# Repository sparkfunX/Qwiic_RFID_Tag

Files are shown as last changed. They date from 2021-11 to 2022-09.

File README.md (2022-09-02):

# SparkX ST25DV64KC Dynamic NFC/RFID Tag

<p align="center">
    <a href="https://github.com/sparkfunX/Qwiic_RFID_Tag/blob/master/LICENSE" alt="License">
        </a>
    <a href="https://twitter.com/intent/follow?screen_name=sparkfun">
                    </a>
</p>

<table class="table table-hover table-striped table-bordered">
    <tr align="center">
     <td></td>
    </tr>
    <tr align="center">
        <td><a href="https://www.sparkfun.com/products/19035">SparkFun Qwiic Dynamic RFID Tag - ST25DV64KC (SPX-19035)</a></td>
    </tr>
</table>

The STMicroelectronics ST25DV _**dynamic**_ Near Frequency Communication / Radio Frequency Identification tag ICs are awesome! The ST25DV64KC offers 64-kBit (8-kBytes) of EEPROM memory which can be accessed over both I2C and RF (NFC)! It's a state-of-the-art tag which conforms to ISO/IEC 15693 or NFC Forum Type 5 recommendations. You can read and write the tag's memory using NFC even while the tag is powered down or disconnected!

The EEPROM memory can be divided into four areas, each of which can have different levels of protection applied. Want to store your data so everyone has read and write access over both I2C and RF? You can do that.
In fact, that's the default! Want to store your data in an area which can only be read if you know the password, and cannot be written to (via RF)? You can do that too!

Our [Arduino Library](https://github.com/sparkfun/SparkFun_ST25DV64KC_Arduino_Library) provides all of the methods you need to read and write the user memory, control the read and write permissions, alter the area sizes and apply password control. Not only that! We've included extra methods which will let you read and write **NDEF (NFC Forum Data Exchange Format) URI, WiFi and Text records** which your smart phone can understand!

Do you want your project to be able to log up to 8-kBytes of data (via I2C) and then be able to read it using your smart phone - even if your project is powered off? Our library lets you do that!

Do you want to be able to write WiFi credentials (SSID and Password) into tag memory using your smart phone and then to be able to read them over I2C so your Arduino board can join the network? With our library you can do that too!

Do you want to be able to manufacture and test your product and then program it with keys or other credentials just before you ship? We've got you covered.

Are you developing equipment or appliances for the home? Would you like to store diagnostic information so that the repair engineer can access it using their smart phone? Our library lets you do that! Would you like the customer to be able to read the diagnostics with _their_ smart phone and then email them to you? Our library will let you do that too! (Apart from the email bit - obvs.. You will need to add that bit yourself.)

Are you designing a poster for your project? Do you want to be able to program your tag using Arduino and then stick it to your poster so people can interact with it? Hey, we've got you covered there too!

## Arduino Library Documentation

A full library use overview, API reference guide and key example walk-throughs are available on GitHub Pages - [sparkfun.github.io/SparkFun_ST25DV64KC_Arduino_Library](https://sparkfun.github.io/SparkFun_ST25DV64KC_Arduino_Library/)

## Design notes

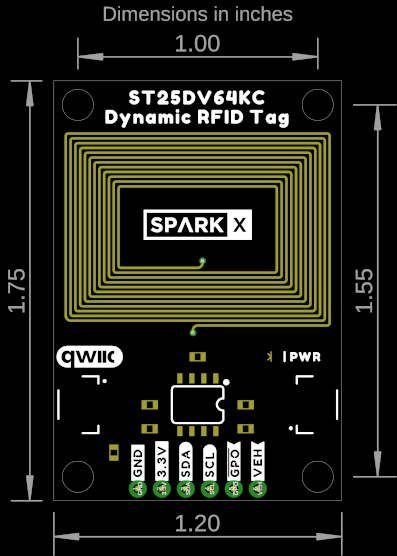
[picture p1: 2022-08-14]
Hardware/Dimensions.png

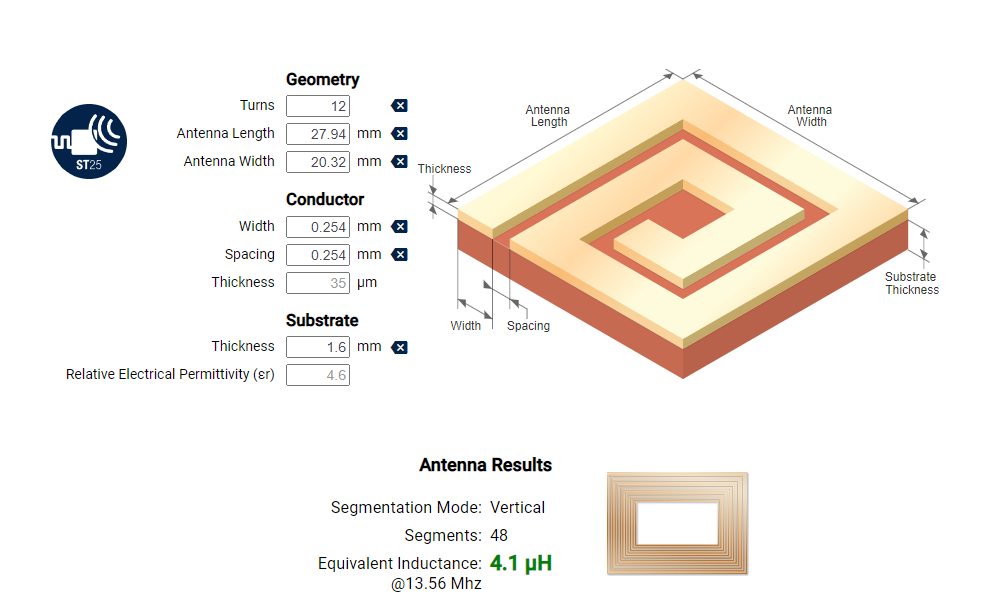
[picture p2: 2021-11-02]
Documents/Antenna design.png

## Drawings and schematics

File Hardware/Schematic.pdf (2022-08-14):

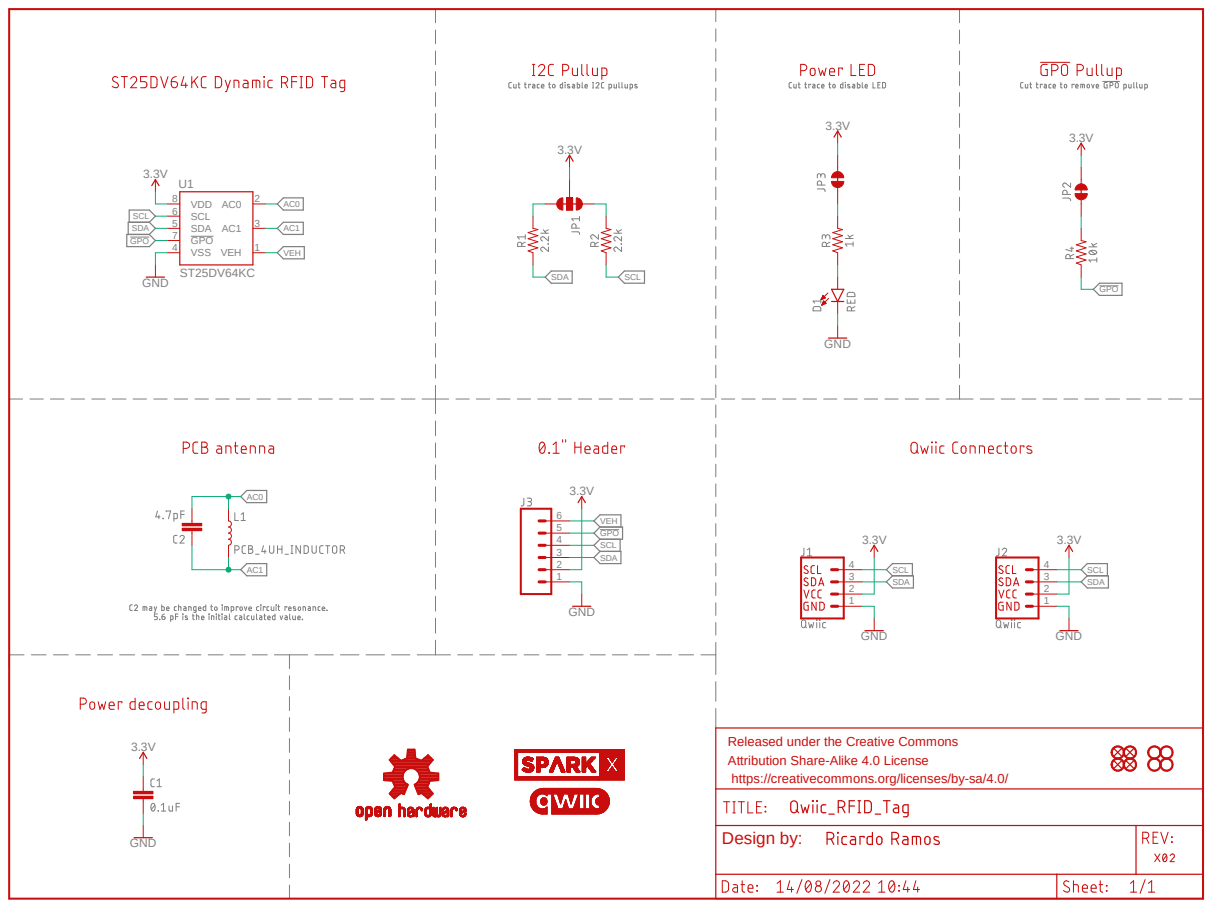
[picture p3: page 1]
GND; VDD 8 SCL 6 SDA 5 GPO 7; VSS 4; VEH; SCL; SDA; GPO; Released under the Creative Commons; Design by:

Attribution Share-Alike 4.0 License
https://creativecommons.org/licenses/by-sa/4.0/

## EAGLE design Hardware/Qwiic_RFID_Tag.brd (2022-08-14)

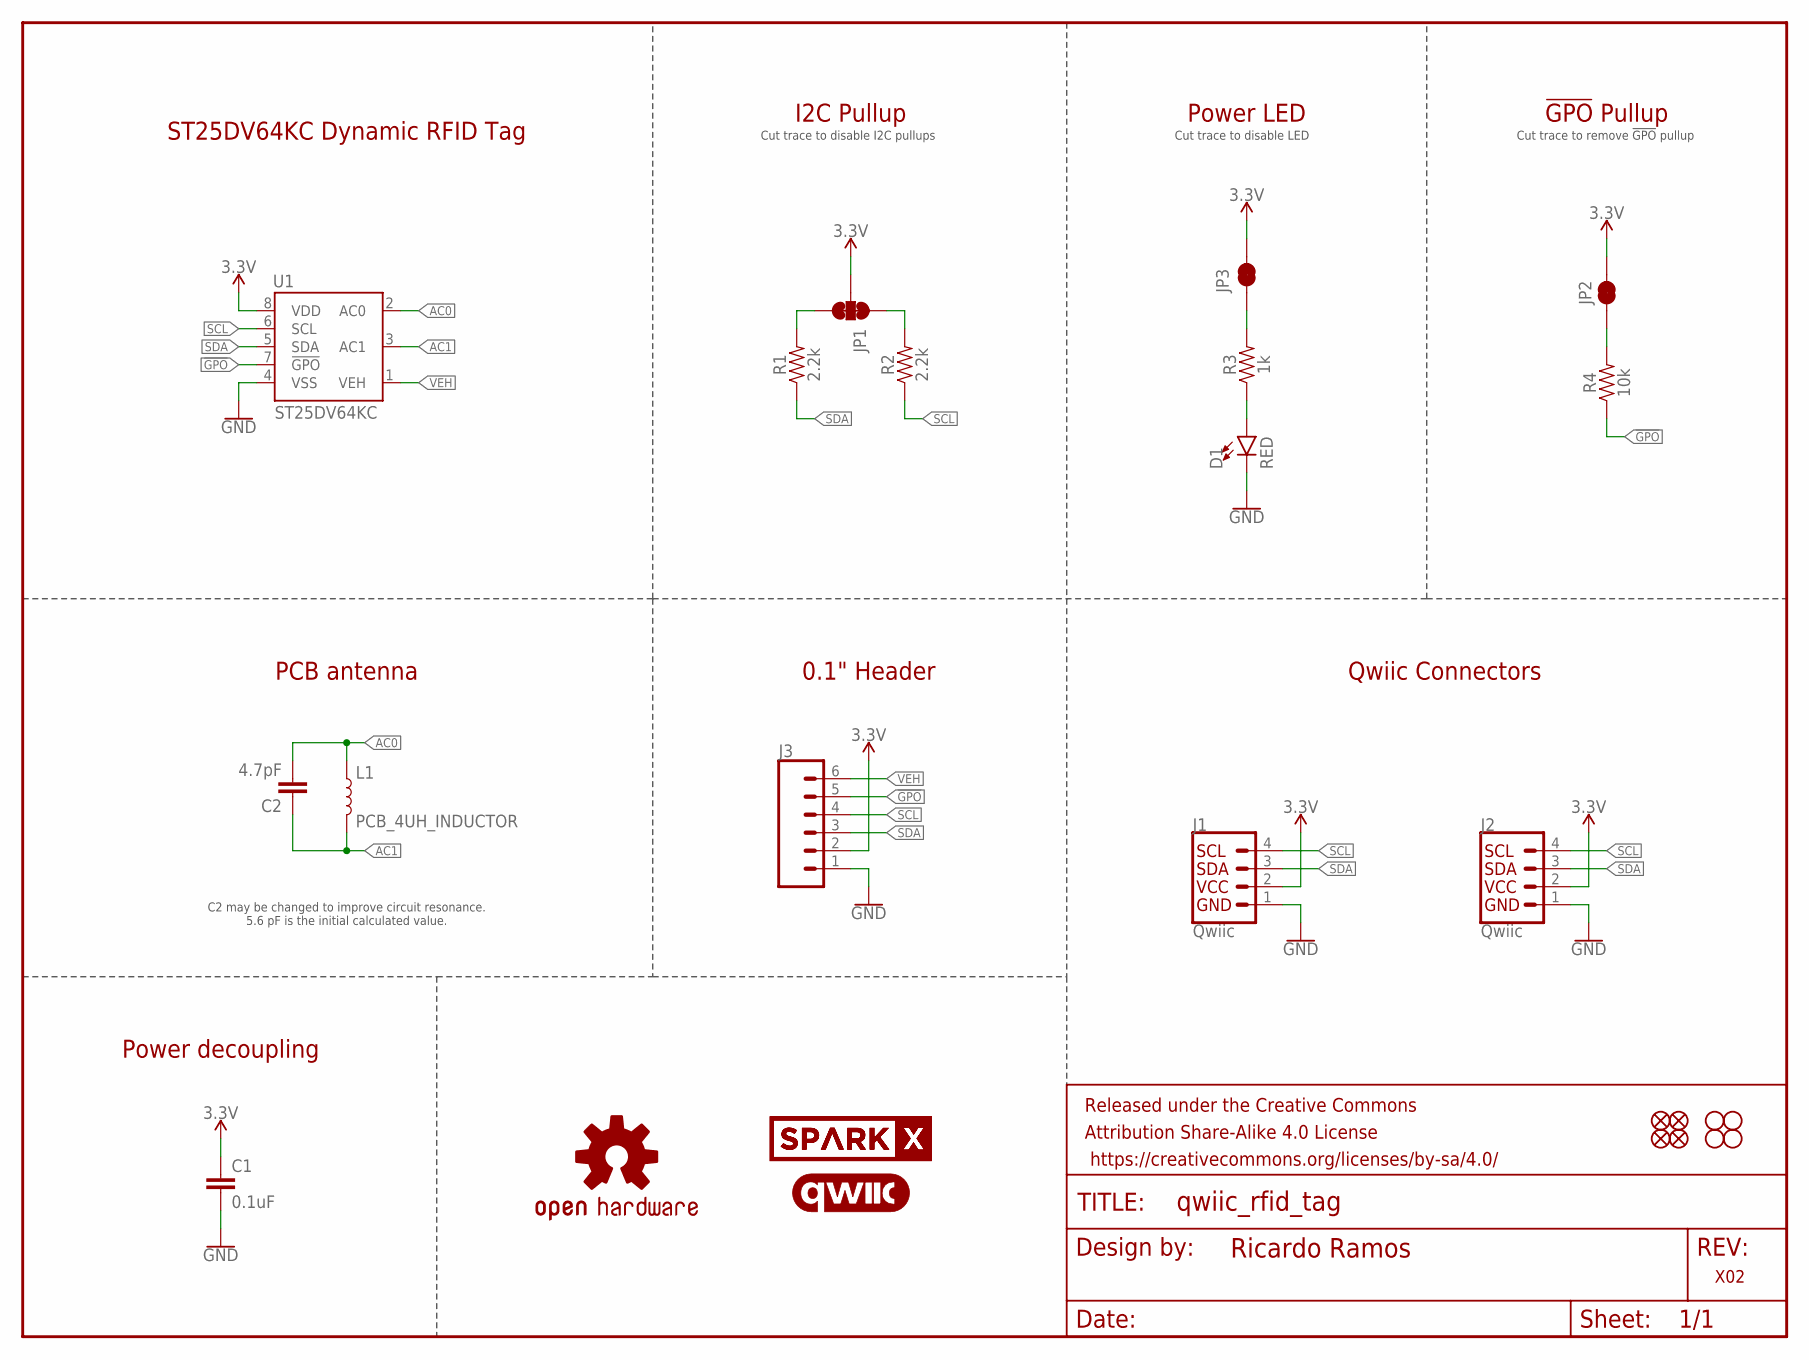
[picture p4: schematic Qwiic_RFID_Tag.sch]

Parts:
C1: 0.1uF; 0603
C2: 4.7pF; 0603
D1: RED; LED-0603
FD1, FD2, FD3, FD4: FIDUCIAL1X2; FIDUCIAL-1X2
FRAME1: FRAME-LETTERNO_PACKAGE; DUMMY
H1, H2, H3, H4: STAND-OFF
J1, J2: Qwiic; JST04_1MM_RA
J3: CONN_06NO_SILK_FEMALE_PTH; 1X06_NO_SILK
JP1: JUMPER-SMT_3_2-NC_TRACE_SILK; SMT-JUMPER_3_2-NC_TRACE_SILK
JP2, JP3: JUMPER-SMT_2_NC_TRACE_SILK; SMT-JUMPER_2_NC_TRACE_SILK
L1: PCB_4UH_INDUCTOR
LOGO1: OSHW-LOGOMINI; OSHW-LOGO-MINI
LOGO3: QWIIC_LOGO_7MM; QWIIC_7MM
R1, R2: 2.2k; 0603
R3: 1k; 0603
R4: 10k; 0603
U1: ST25DV64KC; SO08
U$1, U$2: SPARKX-LOGO5; SPARKX-LARGE

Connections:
3.3V: C1.1, J1.2, J2.2, J3.2, JP1.2, JP2.2, JP3.2, U1.8 (VDD)
!GPO!: J3.5, R4.1, U1.7 (!GPO!)
AC0: C2.2, L1.IN1 (1), U1.2 (AC0)
AC1: C2.1, L1.IN2 (2), U1.3 (AC1)
GND: C1.2, D1.C, J1.1, J2.1, J3.1, U1.4 (VSS)
unnamed: JP3.1, R3.2
unnamed: JP1.3, R1.2
unnamed: JP1.1, R2.2
unnamed: D1.A, R3.1
unnamed: JP2.1, R4.2
SCL: J1.4, J2.4, J3.4, R2.1, U1.6 (SCL)
SDA: J1.3, J2.3, J3.3, R1.1, U1.5 (SDA)
VEH: J3.6, U1.1 (VEH)

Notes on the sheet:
Qwiic Connectors
Cut trace to disable LED
Cut trace to remove !GPO! pullup
0.1" Header
PCB antenna
I2C Pullup
Power LED
!GPO! Pullup
ST25DV64KC Dynamic RFID Tag
Power decoupling
Cut trace to disable I2C pullups
C2 may be changed to improve circuit resonance. 5.6 pF is the initial calculated value.

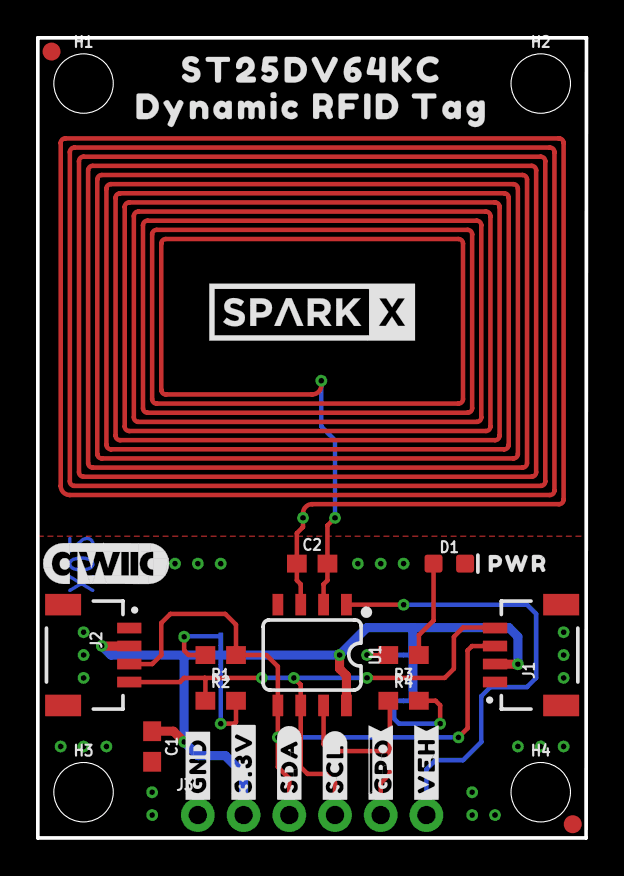
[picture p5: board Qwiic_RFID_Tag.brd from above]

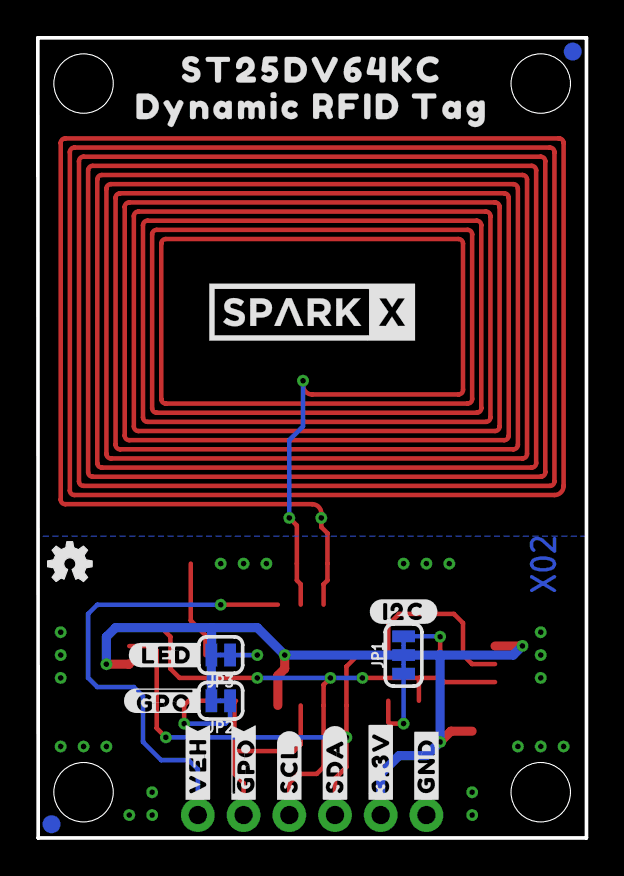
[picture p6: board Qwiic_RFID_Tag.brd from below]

Board: 2 copper layers, 30.5 x 44.5 mm, 48 parts (18 on the bottom side), 13 nets.

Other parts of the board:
U$3, U$19: #3#3V#0
U$4, U$18: #GND#4
U$5, U$20: #SDA#5
U$6, U$21: #SCL#6
U$7, U$22: ##GPO##8
U$8, U$23: #VEH#7
U$9: PWR11
U$10, U$11: DYNAMIC_RFID_TAG0
U$13, U$24: ST25DV64KC5984
U$15: #I2C#11
U$16: ##GPO##9
U$17: #LED#10

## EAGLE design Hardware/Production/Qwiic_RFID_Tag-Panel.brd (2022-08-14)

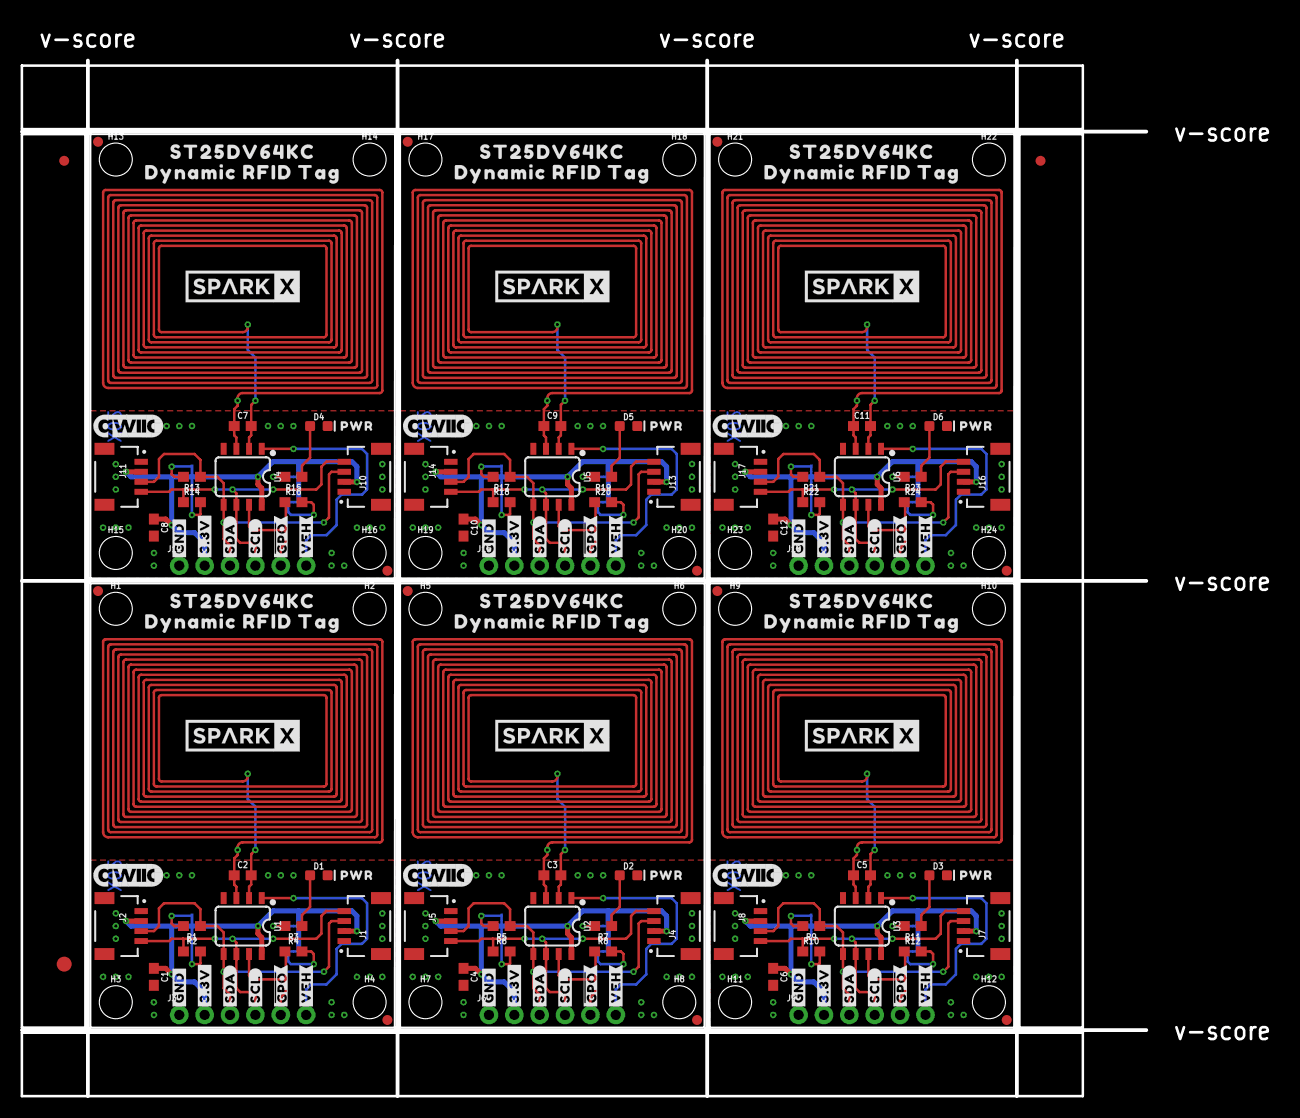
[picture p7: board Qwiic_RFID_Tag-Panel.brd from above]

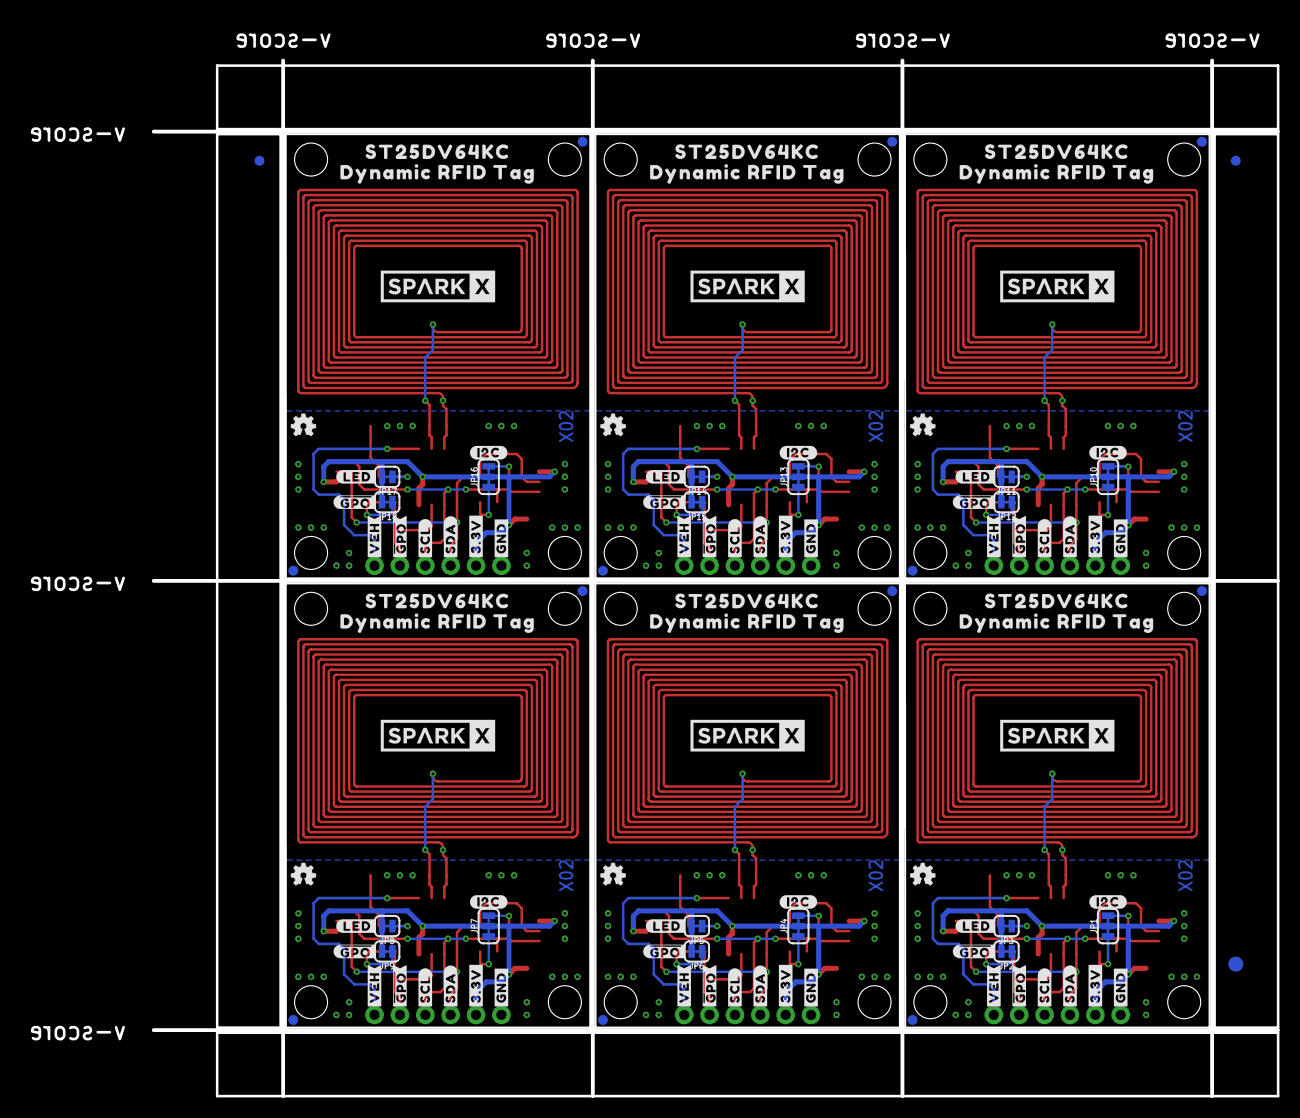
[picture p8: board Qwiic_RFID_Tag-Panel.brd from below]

Board: 2 copper layers, 112.5 x 103.6 mm, 294 parts (111 on the bottom side), 78 nets.

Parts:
C1, C4, C6, C8, C10, C12: 0.1uF; 0603
C2, C3, C5, C7, C9, C11: 4.7pF; 0603
D1, D2, D3, D4, D5, D6: RED; LED-0603
E$1, E$2, E$3, E$4: FIDUCIAL-1X2
E$5, E$6: FIDUCIAL-1.5X3
FD1, FD2, FD3, FD4, FD5, FD6, FD7, FD8, FD9, FD10, FD11, FD12, FD13, FD14, FD15, FD16, FD17, FD18, FD19, FD20, FD21, FD22, FD23, FD24: FIDUCIAL1X2; FIDUCIAL-1X2
FRAME1, FRAME2, FRAME3, FRAME4, FRAME5, FRAME6: FRAME-LETTERNO_PACKAGE; DUMMY
H1, H2, H3, H4, H5, H6, H7, H8, H9, H10, H11, H12, H13, H14, H15, H16, H17, H18, H19, H20, H21, H22, H23, H24: STAND-OFF
J1, J2, J4, J5, J7, J8, J10, J11, J13, J14, J16, J17: Qwiic; JST04_1MM_RA
J3, J6, J9, J12, J15, J18: 1X06_NO_SILK
JP1, JP4, JP7, JP10, JP13, JP16: JUMPER-SMT_3_2-NC_TRACE_SILK; SMT-JUMPER_3_2-NC_TRACE_SILK
JP2, JP3, JP5, JP6, JP8, JP9, JP11, JP12, JP14, JP15, JP17, JP18: JUMPER-SMT_2_NC_TRACE_SILK; SMT-JUMPER_2_NC_TRACE_SILK
L1, L2, L3, L4, L5, L6: PCB_4UH_INDUCTOR
LOGO1, LOGO2, LOGO5, LOGO7, LOGO9, LOGO11: OSHW-LOGOMINI; OSHW-LOGO-MINI
LOGO3, LOGO4, LOGO6, LOGO8, LOGO10, LOGO12: QWIIC_LOGO_7MM; QWIIC_7MM
R1, R2, R5, R6, R9, R10, R13, R14, R17, R18, R21, R22: 2.2k; 0603
R3, R7, R11, R15, R19, R23: 1k; 0603
R4, R8, R12, R16, R20, R24: 10k; 0603
U1, U2, U3, U4, U5, U6: ST25DV64KC; SO08
U$1, U$2, U$12, U$14, U$45, U$46, U$67, U$68, U$89, U$90, U$111, U$112: SPARKX-LOGO5; SPARKX-LARGE
U$3, U$19, U$25, U$36, U$47, U$58, U$69, U$80, U$91, U$102, U$113, U$124: #3#3V#0
U$4, U$18, U$26, U$35, U$48, U$57, U$70, U$79, U$92, U$101, U$114, U$123: #GND#4
U$5, U$20, U$27, U$37, U$49, U$59, U$71, U$81, U$93, U$103, U$115, U$125: #SDA#5
U$6, U$21, U$28, U$38, U$50, U$60, U$72, U$82, U$94, U$104, U$116, U$126: #SCL#6
U$7, U$22, U$29, U$39, U$51, U$61, U$73, U$83, U$95, U$105, U$117, U$127: ##GPO##8
U$8, U$23, U$30, U$40, U$52, U$62, U$74, U$84, U$96, U$106, U$118, U$128: #VEH#7
U$9, U$31, U$53, U$75, U$97, U$119: PWR11
U$10, U$11, U$43, U$44, U$65, U$66, U$87, U$88, U$109, U$110, U$131, U$132: DYNAMIC_RFID_TAG0
U$13, U$24, U$41, U$42, U$63, U$64, U$85, U$86, U$107, U$108, U$129, U$130: ST25DV64KC5984
U$15, U$32, U$54, U$76, U$98, U$120: #I2C#11
U$16, U$33, U$55, U$77, U$99, U$121: ##GPO##9
U$17, U$34, U$56, U$78, U$100, U$122: #LED#10

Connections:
3.3V: C1.1, J1.2, J2.2, J3.2, JP1.2, JP2.2, JP3.2, U1.8
3.3V1: C4.1, J4.2, J5.2, J6.2, JP4.2, JP5.2, JP6.2, U2.8
3.3V2: C6.1, J7.2, J8.2, J9.2, JP7.2, JP8.2, JP9.2, U3.8
3.3V3: C8.1, J10.2, J11.2, J12.2, JP10.2, JP11.2, JP12.2, U4.8
3.3V4: C10.1, J13.2, J14.2, J15.2, JP13.2, JP14.2, JP15.2, U5.8
3.3V5: C12.1, J16.2, J17.2, J18.2, JP16.2, JP17.2, JP18.2, U6.8
!GPO!: J3.5, R4.1, U1.7
!GPO!1: J6.5, R8.1, U2.7
!GPO!2: J9.5, R12.1, U3.7
!GPO!3: J12.5, R16.1, U4.7
!GPO!4: J15.5, R20.1, U5.7
!GPO!5: J18.5, R24.1, U6.7
AC0: C2.2, L1.IN1, U1.2
AC1: C2.1, L1.IN2, U1.3
AC2: C3.2, L2.IN1, U2.2
AC3: C3.1, L2.IN2, U2.3
AC4: C5.2, L3.IN1, U3.2
AC5: C5.1, L3.IN2, U3.3
AC6: C7.2, L4.IN1, U4.2
AC7: C7.1, L4.IN2, U4.3
AC8: C9.2, L5.IN1, U5.2
AC9: C9.1, L5.IN2, U5.3
AC10: C11.2, L6.IN1, U6.2
AC11: C11.1, L6.IN2, U6.3
GND: C1.2, D1.C, J1.1, J2.1, J3.1, U1.4
GND1: C4.2, D2.C, J4.1, J5.1, J6.1, U2.4
GND2: C6.2, D3.C, J7.1, J8.1, J9.1, U3.4
GND3: C8.2, D4.C, J10.1, J11.1, J12.1, U4.4
GND4: C10.2, D5.C, J13.1, J14.1, J15.1, U5.4
GND5: C12.2, D6.C, J16.1, J17.1, J18.1, U6.4
unnamed: JP3.1, R3.2
unnamed: JP1.3, R1.2
unnamed: JP1.1, R2.2
unnamed: D1.A, R3.1
unnamed: JP2.1, R4.2
unnamed: JP4.3, R5.2
unnamed: JP4.1, R6.2
unnamed: JP5.1, R7.2
unnamed: D2.A, R7.1
unnamed: JP6.1, R8.2
unnamed: JP7.3, R9.2
unnamed: JP7.1, R10.2
unnamed: JP8.1, R11.2
unnamed: D3.A, R11.1
unnamed: JP9.1, R12.2
unnamed: JP10.3, R13.2
unnamed: JP10.1, R14.2
unnamed: JP11.1, R15.2
unnamed: D4.A, R15.1
unnamed: JP12.1, R16.2
unnamed: JP13.3, R17.2
unnamed: JP13.1, R18.2
unnamed: JP14.1, R19.2
unnamed: D5.A, R19.1
unnamed: JP15.1, R20.2
unnamed: JP16.3, R21.2
unnamed: JP16.1, R22.2
unnamed: JP17.1, R23.2
unnamed: D6.A, R23.1
unnamed: JP18.1, R24.2
SCL: J1.4, J2.4, J3.4, R2.1, U1.6
SCL1: J4.4, J5.4, J6.4, R6.1, U2.6
SCL2: J7.4, J8.4, J9.4, R10.1, U3.6
SCL3: J10.4, J11.4, J12.4, R14.1, U4.6
SCL4: J13.4, J14.4, J15.4, R18.1, U5.6
SCL5: J16.4, J17.4, J18.4, R22.1, U6.6
SDA: J1.3, J2.3, J3.3, R1.1, U1.5
SDA1: J4.3, J5.3, J6.3, R5.1, U2.5
SDA2: J7.3, J8.3, J9.3, R9.1, U3.5
SDA3: J10.3, J11.3, J12.3, R13.1, U4.5
SDA4: J13.3, J14.3, J15.3, R17.1, U5.5
SDA5: J16.3, J17.3, J18.3, R21.1, U6.5
VEH: J3.6, U1.1
VEH1: J6.6, U2.1
VEH2: J9.6, U3.1
VEH3: J12.6, U4.1
VEH4: J15.6, U5.1
VEH5: J18.6, U6.1

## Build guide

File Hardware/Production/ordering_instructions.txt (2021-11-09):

panel size, 107x104mm
PCB thickness, 1.6mm
number of layers, 2
soldermask color, Black
silkscreen color, White
oz copper, 1oz
finish, HASL lead free
stencils, top
pcs per panel, 6
min trace width, 0.2540mm / 0.0100in
min drill size, 0.3048mm / 0.0120in

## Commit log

2021-11-02 Initial version
    [Qwiic_RFID_Tag.brd, Qwiic_RFID_Tag.sch]
2021-11-03 Fixed misaligned mounting hole; trimmed long schematic segment.
    [Qwiic_RFID_Tag.brd, Qwiic_RFID_Tag.sch]
2021-11-03 Fixed wrong dimension callout.
    [Qwiic_RFID_Tag.brd]
2021-11-04 Fixed fiducial placement, board version size and polygon isolation.
    [Qwiic_RFID_Tag.brd]
2021-11-04 Created production files
    [Qwiic_RFID_Tag-Panel.GBL, Qwiic_RFID_Tag-Panel.GBO, Qwiic_RFID_Tag-Panel.GBP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]
2021-11-09 Created PCB production files.
    [Qwiic_RFID_Tag-Panel.GBL, Qwiic_RFID_Tag-Panel.GBO, Qwiic_RFID_Tag-Panel.GBS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]
2021-11-09 Renamed file to reflect version. Added PCB version to bottom silk.
    [Qwiic_RFID_Tag-Panel.GBO, Qwiic_RFID_Tag_X01-Panel.GBL, Qwiic_RFID_Tag_X01-Panel.GBO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]
2021-11-09 Added bom csv file.
    [bom_output.csv]
2021-11-24 Added production files; updated BOM.
    [Qwiic_RFID_Tag_X01-Panel.brd, Qwiic_RFID_Tag_X01.brd, bom_output.csv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]
2022-08-14 Add schematic
2022-08-14 X02 PCB
    [Qwiic_RFID_Tag-Panel.GBL, Qwiic_RFID_Tag-Panel.GBO, Qwiic_RFID_Tag-Panel.GBP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]

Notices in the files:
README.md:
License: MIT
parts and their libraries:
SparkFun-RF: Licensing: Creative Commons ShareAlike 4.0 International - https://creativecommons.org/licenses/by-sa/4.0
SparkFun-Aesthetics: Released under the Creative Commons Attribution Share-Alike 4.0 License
